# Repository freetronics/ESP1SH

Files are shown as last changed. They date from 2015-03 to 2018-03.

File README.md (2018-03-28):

Freetronics ESP8266 / ESP-01 (WiFi) Breakout Shield
===================================================
Copyright 2014-2017 Freetronics Pty Ltd www.freetronics.com  

A shield for the Arduino and other microcontroller boards based on the
same header format, such as the Freetronics Eleven. Includes a header
to mount an ESP-01 module containing an ESP8266 WiFi chipset and
supporting parts, giving your Arduino WiFi capabilities.

Includes level shifters to allow safe operation on both 3.3V and 5V
Arduino boards.

More information is available on our product page at:

  http://www.freetronics.com/esp1sh

http://tminusarduino.blogspot.com.au/2014/09/experimenting-with-esp8266-5-wifi-module.html

INSTALLATION
------------
The design is saved as an EAGLE project. EAGLE PCB design software is
available from www.cadsoftusa.com free for non-commercial use. To use
this project download it and place the directory containing these files
into the "eagle" directory on your computer. Then open EAGLE and
navigate to the project.

DISTRIBUTION
------------
The specific terms of distribution of this project are governed by the
license referenced below.

LICENSE
-------
Licensed under the TAPR Open Hardware License (www.tapr.org/OHL).
The "license" folder within this repository also contains a copy of
this license in plain text format.

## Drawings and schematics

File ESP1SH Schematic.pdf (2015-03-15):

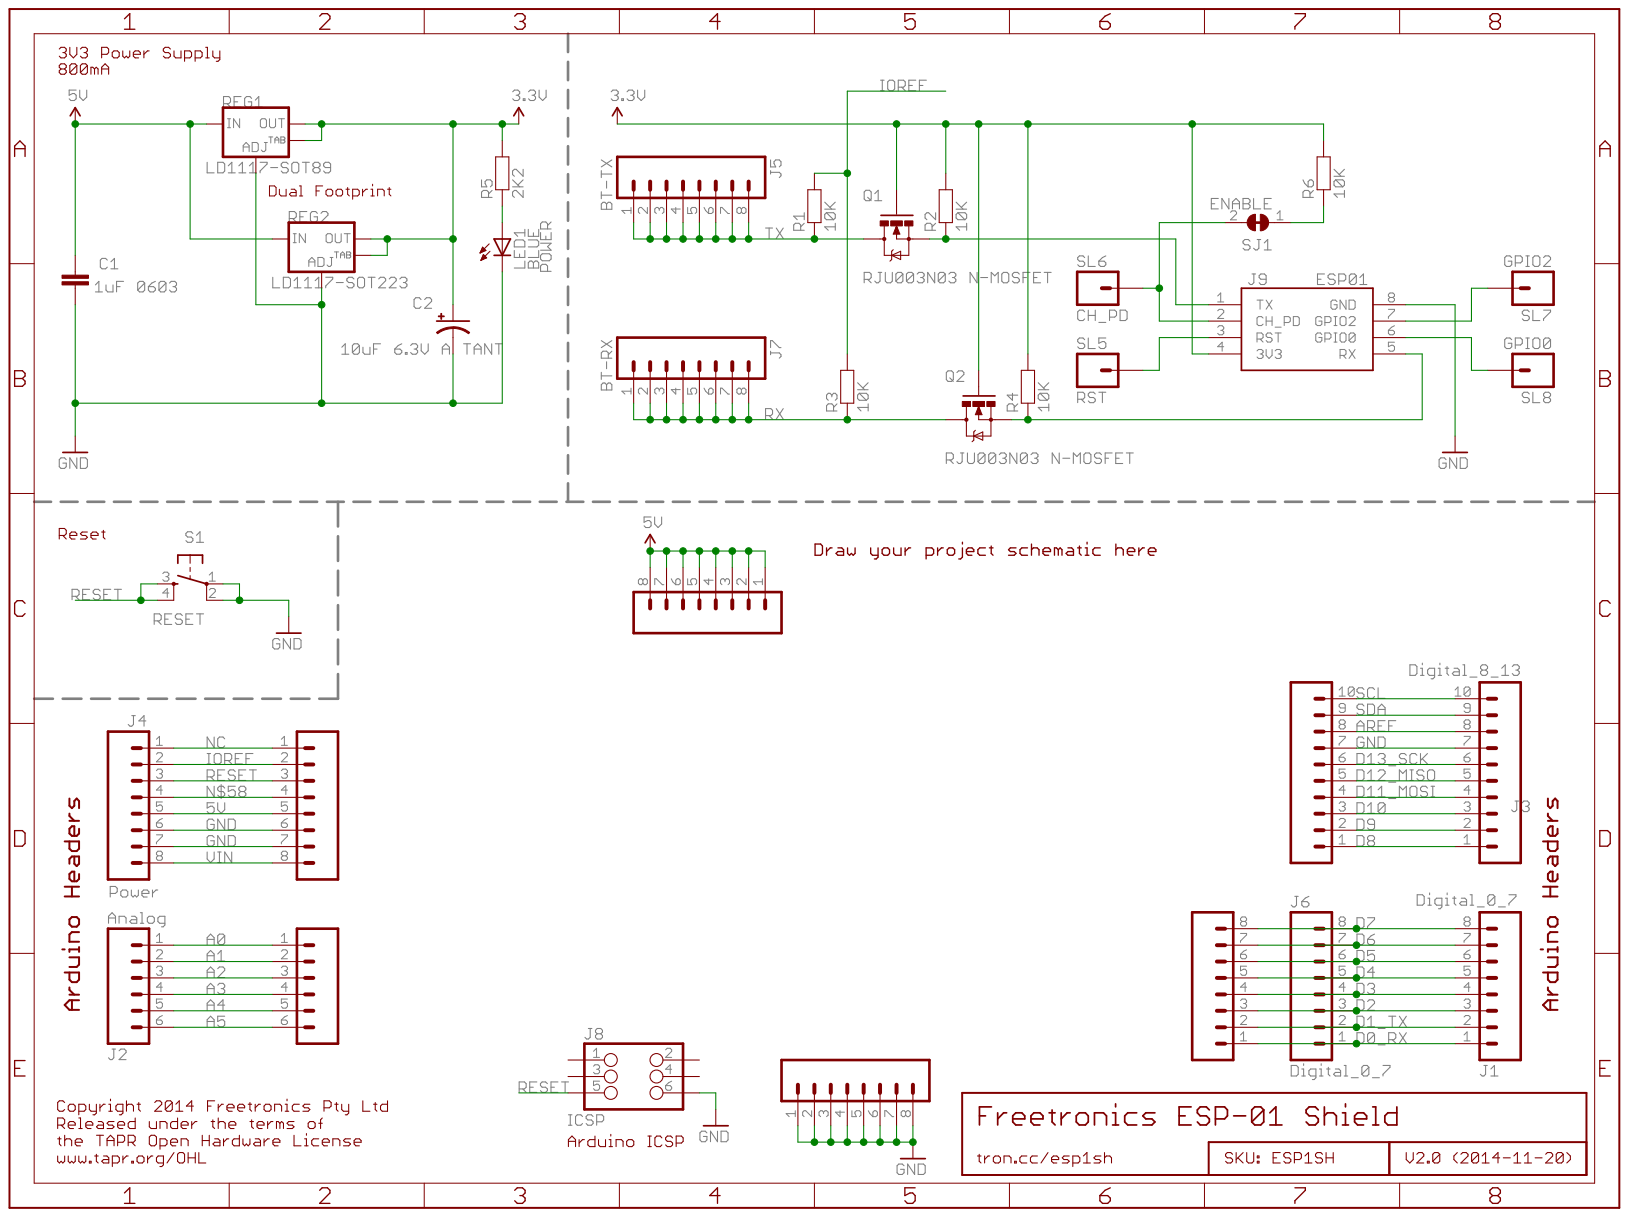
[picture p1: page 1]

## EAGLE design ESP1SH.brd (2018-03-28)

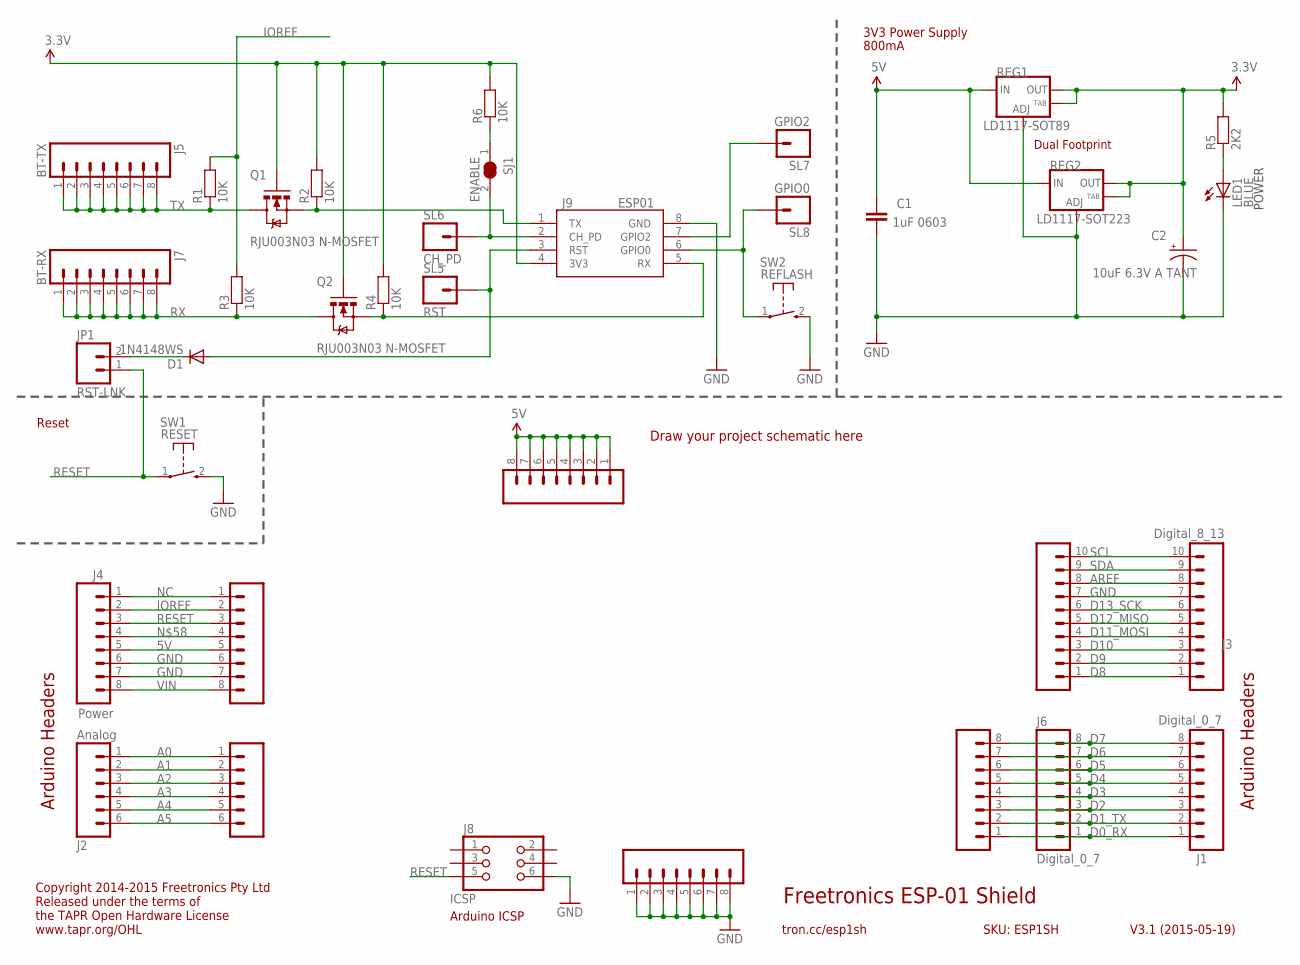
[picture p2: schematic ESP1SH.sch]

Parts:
C1: 1uF 0603; 0603
C2: 10uF 6.3V A TANT; EIA3216
D1: 1N4148WS; SOD-323
J1, J6: Digital_0_7; 1X08
J2: Analog; 1X06
J3: Digital_8_13; 1X10
J4: Power; 1X08
J5: BT-TX; 1X08
J7: BT-RX; 1X08
J8: ICSP; 2X03PTH
J9: ESP01
JP1: RST-LNK; 1X02
LED1: BLUE; LED-0603
Q1, Q2: RJU003N03 N-MOSFET; SOT32-3
R1, R2, R3, R4, R6: 10K; 0603
R5: 2K2; 0603
REG1: LD1117-SOT89; SOT89
REG2: LD1117-SOT223; SOT223
SJ1: ENABLE; SJC
SL1: Digital_0_7; 1X08
SL2: Analog; 1X06
SL3: Digital_8_13; 1X10
SL4: Power; 1X08
SL5: RST; 1X01
SL6: CH_PD; 1X01
SL7: GPIO2; 1X01
SL8: GPIO0; 1X01
SL9: GND; 1X08
SL10: 5V; 1X08
SW1: RESET; TACTILE_SWITCH_SMD_2PIN_TINY
SW2: REFLASH; TACTILE_SWITCH_SMD_2PIN_TINY

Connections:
3.3V: C2.A (+), J9.4 (3V3), Q1.1 (G), Q2.1 (G), R2.2, R4.2, R5.2, R6.2, REG1.2 (OUT), REG1.4 (OUT), REG2.2 (OUT), REG2.4 (OUT)
5V: C1.1, J4.5, REG1.3 (IN), REG2.3 (IN), SL4.5, SL10.1, SL10.2, SL10.3, SL10.4, SL10.5, SL10.6, SL10.7, SL10.8
A0: J2.1, SL2.1
A1: J2.2, SL2.2
A2: J2.3, SL2.3
A3: J2.4, SL2.4
A4: J2.5, SL2.5
A5: J2.6, SL2.6
AREF: J3.8, SL3.8
D0_RX: J1.1, J6.1, SL1.1
D1_TX: J1.2, J6.2, SL1.2
D2: J1.3, J6.3, SL1.3
D3: J1.4, J6.4, SL1.4
D4: J1.5, J6.5, SL1.5
D5: J1.6, J6.6, SL1.6
D6: J1.7, J6.7, SL1.7
D7: J1.8, J6.8, SL1.8
D8: J3.1, SL3.1
D9: J3.2, SL3.2
D10: J3.3, SL3.3
D11_MOSI: J3.4, SL3.4
D12_MISO: J3.5, SL3.5
D13_SCK: J3.6, SL3.6
GND: C1.2, C2.C (-), J3.7, J4.6, J4.7, J8.6, J9.8 (GND), LED1.C, REG1.1 (ADJ), REG2.1 (ADJ), SL3.7, SL4.6, SL4.7, SL9.1, SL9.2, SL9.3, SL9.4, SL9.5, SL9.6, SL9.7, SL9.8, SW1.2 (S), SW2.2 (S)
IOREF: J4.2, R1.2, R3.2, SL4.2
unnamed: J9.6 (GPIO0), SL8.1, SW2.1
unnamed: J9.7 (GPIO2), SL7.1
unnamed: D1.2 (A), J9.3 (RST), SL5.1
unnamed: J9.2 (CH_PD), SJ1.2, SL6.1
unnamed: LED1.A, R5.1
unnamed: J9.1 (TX), Q1.2 (S), R2.1
unnamed: J9.5 (RX), Q2.2 (S), R4.1
unnamed: J4.4, SL4.4
unnamed: R6.1, SJ1.1
unnamed: D1.1 (C), JP1.2
NC: J4.1, SL4.1
RESET: J4.3, J8.5, JP1.1, SL4.3, SW1.1
RX: J7.1, J7.2, J7.3, J7.4, J7.5, J7.6, J7.7, J7.8, Q2.3 (D), R3.1
SCL: J3.10, SL3.10
SDA: J3.9, SL3.9
TX: J5.1, J5.2, J5.3, J5.4, J5.5, J5.6, J5.7, J5.8, Q1.3 (D), R1.1
VIN: J4.8, SL4.8

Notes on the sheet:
Freetronics ESP-01 Shield
V3.1 (2015-05-19)
tron.cc/esp1sh
SKU: ESP1SH
Arduino Headers
Reset
Draw your project schematic here
Arduino ICSP
Copyright 2014-2015 Freetronics Pty Ltd Released under the terms of the TAPR Open Hardware License www.tapr.org/OHL
POWER
3V3 Power Supply
Dual Footprint
800mA

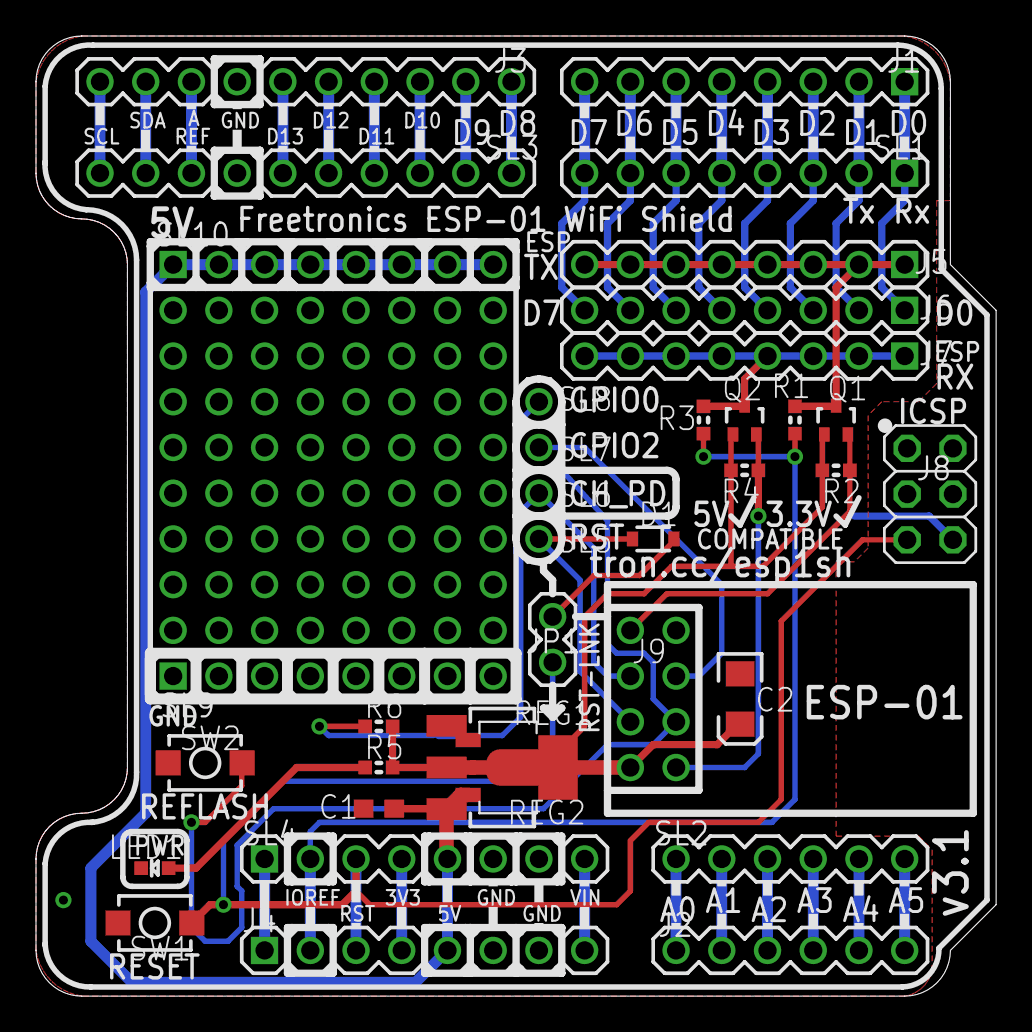
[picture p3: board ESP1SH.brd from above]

Board: 2 copper layers, 53.3 x 53.3 mm, 37 parts (1 on the bottom side), 42 nets.

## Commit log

2014-11-19 Version 1.0 release
    [ESP1SH.brd, ESP1SH.sch]
2015-02-05 Added onboard voltage regulator for v1.1 release
    [ESP1SH.brd, ESP1SH.sch]
2015-03-15 Add schematic PDF
2015-05-19 Added REFLASH button connected to CH_PD
    [ESP1SH.brd, ESP1SH.sch]
2015-05-19 Changed REFLASH button from CH_PD to GPIO0
    [ESP1SH.brd, ESP1SH.sch]
2018-03-28 Board updates for v3.1 release
    [ESP1SH.brd]

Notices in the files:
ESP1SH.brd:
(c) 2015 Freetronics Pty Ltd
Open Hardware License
